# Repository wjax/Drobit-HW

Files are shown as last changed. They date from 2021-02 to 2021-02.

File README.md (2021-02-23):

# Drobit-HW
 This repository contains the electronic design and BOM files of the Drobit HW ecosystem.

 Drobit is a PPK (Post Processing Kinematics) solution for the UAV industry. Drobit allows to precisely geotag pictures taken by a camera on board the UAV allowing GCP-free (ground control point) photogrammetry surveys.

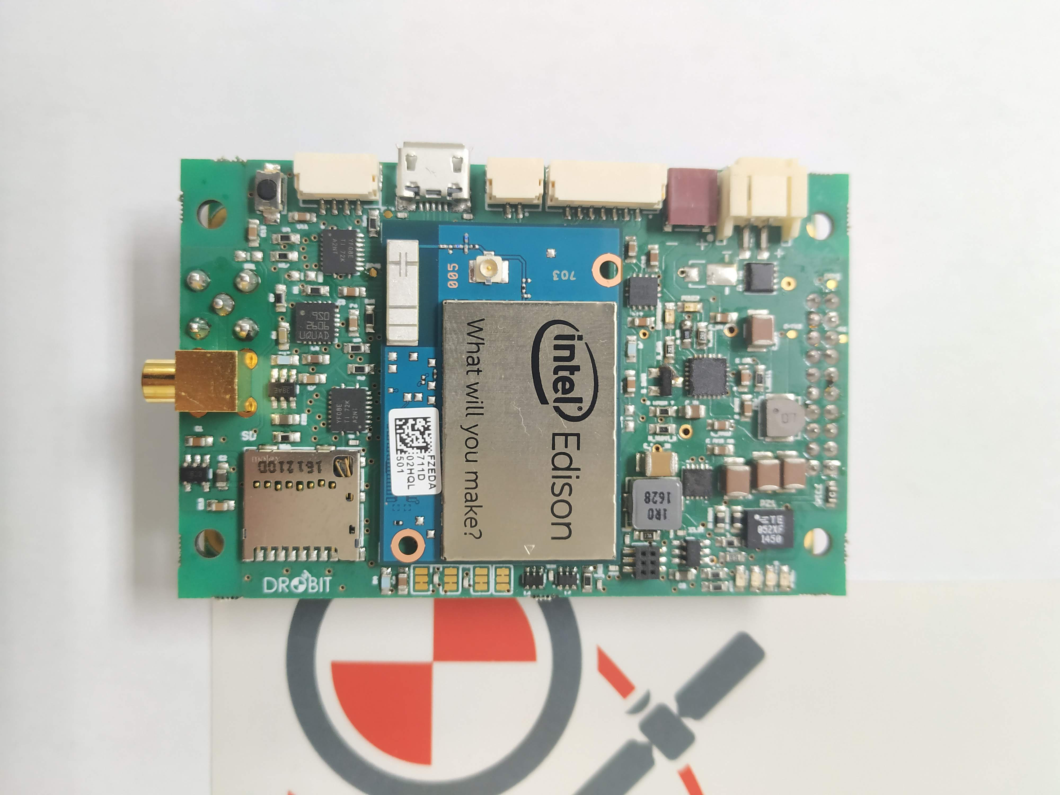
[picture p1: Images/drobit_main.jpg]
Drobit main board Drobit Main
  

 Drobit HW ecosystem is:
 * Drobit Main board
    * Intel Edison CPU
    * Dual-Freq GNSS Board from ComNav
    * 9Dof IMU
    * Batttery management 
 * Drobit Hotshoe board
    * Camera flash signal conditioning
    * 9Dof IMU 
 * Optional: External Button-LED board for cases
 * Optional: Micro connector breakboard

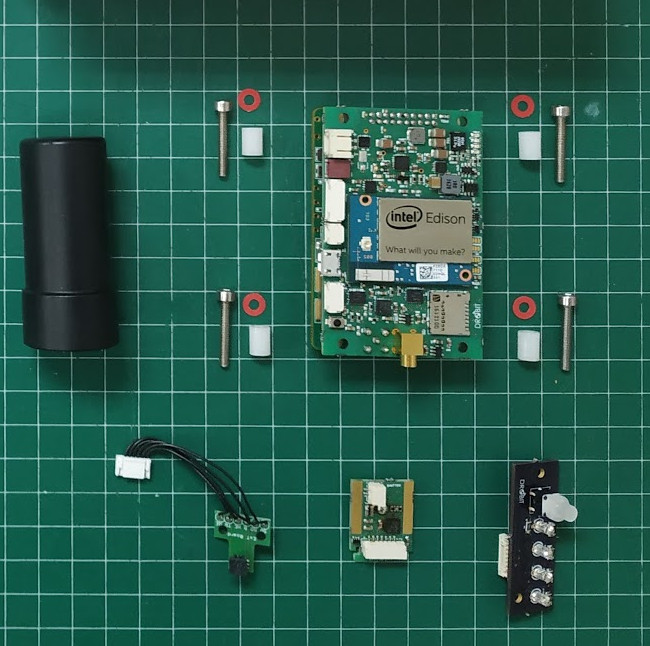
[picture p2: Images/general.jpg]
Drobit components
 
 
 ## History
 Drobit was created in 2016 by Jose Martinez Rubio and Jesús Alvarez in order to overcome one of the main limitations when doing UAV Photogrammetry applied to big survey areas.... the manual positioning of GCPs.

 Drobit has been used too as *Drobit Inspector* for Civil infrastructure inspection.

 As of today, Drobit has finished its commercial life and we decided to opensource both HW and SW.

 ## Theory of operation
 The idea behind drobit is to provide aerial imagery with super precise WGS84 coordinates of the lens nodal point. If that's the case, photogrammetry software like Agisoft Metashaper or Pix4D can reconstruct the terrain 3D model with centimeter accuracy (with no GCP).

 In order to do that Drobit incorporates a Dual Frequency Survey grade GPS (ComNav 501G) with a Heical Harxon Dual frecuency Antenna that provides 20Hz RAW GNSS observations. We will use Differential GPS as the main source of precise geopositioning.
 It also contains two 9dof IMU, one in the drobit main board and one in the drobit hotshoe board.

 The hotshoe board will be inserted into the camera hotshoe and will provide precise timing for every picture by sensing the flash trigger.

 In a photogrammetry UAV flight, drobit will record GNSS observations (for later postprocessing PPK) and will capture IMU orientation for both drobit main board and hotshoe board.

## Post Processing (PPK and coordinates translation)
 Later, in the office, Drobit PPK Software will obtain precise GPS (WGS84) coordinates from the antenna phase center by resolving the PPK against a GNSS Base receiver (Drobit base or any other manufacturer base with Rinex, even a CORS).

 In order to obtain the nodal camera point position, Drobit PPK Software needs to translate the GNSS antenna coordinate using IMU values and X,Y,Z offsets.

 Once finished, pictures are geotagged and a file containing picture name and precise coordinates is generated.

 Drobit PPK Software creates an kmz for google earth that allows to see cameras oriented and located in 3d space.

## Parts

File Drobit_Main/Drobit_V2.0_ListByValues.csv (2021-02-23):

Qty | Value | Part Num | Package | Parts
4 |  | * | PAD-JUMPER-3-2OF3_NC_BY_TRACE_YES_SILK_FULL_BOX | JP-DCIN, JP-ENABLE-UART2, JP-SCL, JP-SDA
1 |  | 455-1564-1-ND | JST-GH-2 | TRIG-IN
1 |  | 455-1566-1-ND | JST-GH-4 | UART-EXT
1 |  | 455-1569-1-ND | JST-GH-7 | TRIG-OUT
1 |  | 455-2524-1-ND | SM02B-SFHRS-TF | BATT
1 |  | 523-A-1JB | U.FL-A-1JB | X1
5 | 0.1UF | 810-CGA3E2X7R1E104K | 0603-CAP | C4, C7, C11, C12, C13
1 | 0.22UF | 810-C1608X7R1C224K | 0603-CAP | C5
1 | 0.033uF | 810-CGA3E2X7R1H333MA | 0603-CAP | C_BOOT
6 | 1.0UF | 810-CGA3E1X7R1E105K | 0603-CAP | C1, C3, C9, C10, C14, C_BAT
1 | 1.5uH | 81-FDSD0420-H-1R5MP3 | FDSD0420 | L_SW
1 | 1.8K | 667-ERJ-3GEYJ182V | 0603-RES | R_CHG
1 | 1.8K | 667-ERJ-3GEYJ182V | 0603-RES | R_PG
1 | 1UF | 810-CGA3E1X7R1E105K | 0603-CAP | C_PMID
2 | 2.2UF | 810-CGA3E1X5R1C225K | 0603-CAP | C15, C_DRV
2 | 4.7K | * | 0603-RES | R51, R52
1 | 4.7UF | 81-GRM18R60J475KE19D | 0603-CAP | C6
1 | 4.7UF | 810-C2012X5R1E226M | 0603-CAP | C_IN
1 | 10K | 667-ERJ-3EKF1002V | 0603-RES | R_VDPM_B
10 | 10K | 667-ERJ-3EKF1002V | 0603-RES | R1, R2, R3, R5, R6, R15, R17, R61, R62, R_ISET1
1 | 10NF | 810-CGA3E2X7R1H103K | 0603-CAP | C16
3 | 10UF | 810-C3225X7R1E106K | 1210 | C_DC5_OUT1, C_DC5_OUT2, C_OUTS
1 | 10UF | 810-C3225X7R1E106K | 1210 | C_SYS
3 | 10UF | 810-CGA4J1X5R1C106K | 0603-CAP | C2, C8, C22
1 | 22UF | 81-GRM32ER61E226ME5L | 1210 | C_DC5_IN
1 | 47K | 754-RR0816P-473D | 0603-RES | R10
1 | 71.5K | 667-ERJ-3EKF7152V | 0603-RES | R_VDPM_T
1 | 82 | 667-ERJ-3EKF82R0V | 0603-RES | R28
3 | 100K | 754-RR0510P-104D | 0603-RES | R4, R7, R18
2 | 105 | 667-ERJ-3EKF1050V | 0603-RES | R20, R24
1 | 180 | 667-ERJ-3GEYJ181V | 0603-RES | R19
1 | 270NF | 81-GRM188R71C274KA1D | 0603-CAP | C_DC5_SS
2 | 287 | 667-ERJ-3EKF2870V | 0603-RES | R9, R16
1 | 590 | 754-RR1220P-5900D-M | 0603-RES | R_ISET
1 | 0603L010YR | 576-0603L010YR | 0602 | PTC1
1 | 10103594-0001LF | 649-10103594-0001LF | POS-5 | USB
1 | BAT54C | 512-BAT54C | SOT23 | D_IUSB
2 | BLM18SG221TZ1-2.5A | 81-BLM18SG221TZ1D | 0603 | BLM5V1, BLM5V2
1 | BLUE - APT1608VBC/D | 604-APT1608VBC/D | LED-0603 | D-TRIGGER
1 | BQ24266 | 595-BQ24266RGER | QFN50P400X400X100-25N | CHARGER
2 | BSS138PS | 771-BSS138BKS115 | SOT363 | T2, T3
1 | COMNAV_501G | * | COMNAV_501G | U$1
1 | EDISON_CONNECTOR_FULLMOUNTING_HOLES | 798-DF40C70DS04V51 | EDISON_DAUGHTER | U2
1 | FR014H5JZ | 512-FR014H5JZ | FR014H5JZ | P_IN
1 | HM-TRLR-S | * | HM-TRLR-S | LINK
1 | JST_PH_G | 455-1749-1-ND | JST-PH-2-SMT-RA | PWR
1 | JUMPER-PAD-2-NOYES_SILK | * | PAD-JUMPER-2-NO_YES_SILK | JP_LINK
1 | LSM9DS0 | 497-13902-1-ND | LGA-24 | U1
10 | LXES15AAA1-133 | 81-LXES15AAA1-133 | 1005 | TVS1, TVS2, TVS3, TVS4, TVS5, TVS6, TVS7, TVS8, TVS9, TVS10
1 | M40-3100345R | 855-M40-3100345R | M40-3100345R | EXT-INTERFACE
1 | MCX-TECON-1-1337586-0 | 571-1-1337586-0 | 1-1337586-0 | U$2
2 | MIC2039 | 998-MIC2039EYM6T5 | SOT23-6 | 5VACCLIM, USBREG
1 | MIC52053.3V | 998-MIC5205-3.3YM5TR | SOT23-5 | U4
2 | ORANGE - APT1608SECK/J4-PRV | 604-APT1608SECKJ4PRV | LED-0603 | CHARGING, D-REC
1 | ROJO - APT1608SECK/J3- | 604-APT1608SECKJ3PRV | LED-0603 | POWER
1 | ROJO - APT1608SECK/J3-PRV | 604-APT1608SECKJ3PRV | LED-0603 | D-ON
1 | SDCARD | 538-104031-0811 | 1040310811 | SD
1 | SKRKAEE010 | 688-SKRKAE | SKRKAEE010 | SREC
1 | SPR5030T-1R0 | 652-SRP5030T-1R0M | SRP5030T-1R0 | L_DC5_SW
1 | TPS61232 | 595-TPS61232DRCR | SON-10 | DC5V
1 | TPS73501DRBT | 595-TPS73501DRBR | SON65P300X300X100-9N | DC3VLINK
5 | TPTP08R | * | TP08R | C-RX2, C-TX2, GP45, GP46, PPS
2 | TXS0108 | 595-TXS0108ERGYR | R-PVQFN-N20 | U7, U9
1 | V8PAN50-M3/I | 78-V8PAN50-M3/I | V8PAN50-M3/I | D_IN
1 | VERDE - APT1608ZGCK | 604-APT1608ZGCK | LED-0603 | D-SAT
1 | ZEN056V230A16YC | 650-ZEN056V230A16YC | ZEN056V230A16YC | PZ1

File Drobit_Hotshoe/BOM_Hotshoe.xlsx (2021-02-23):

ZAPATA PLACA PEQUEÑA
Qty x Placa | NUMERO | Value | Part Num | Package | Parts | Cantidad Total
1 | 1 |  | 455-1564-1-ND | JST-GH-2 | SHUTTER | 50 | Ojo Posicion. Huella no igual que placa grande
1 | 3 |  | 455-1569-1-ND | JST-GH-7 | DROBIT-IO | 50
1 | 6 | 0.1UF | 810-CGA3E2X7R1E104K | 0603-CAP | C4 | 135
1 | 7 | 0.22UF | 810-C1608X7R1C224K | 0603-CAP | C5 | 50
1 | 9 | 1.0UF | 810-CGA3E1X7R1E105K | 0603-CAP | C3 | 180
2 | 101 | 4.7K | 667-ERJ-3GEYJ472V | 0603-RES | R21, R22 | 50
1 | 15 | 4.7UF | 81-GRM18R60J475KE19D | 0603-CAP | C6 | 50
1 | 102 | 10K | 667-EXB-38V103JV | 0603-ARV | R1 | 25
1 | 39 | BSS138PS | 771-BSS138BKS115 | SOT363 | T1 | 75
1 | 43 | LSM9DS0 | 497-13902-1-ND | LGA-24 | U1 | 50
 |  | Compartidos ambas placas

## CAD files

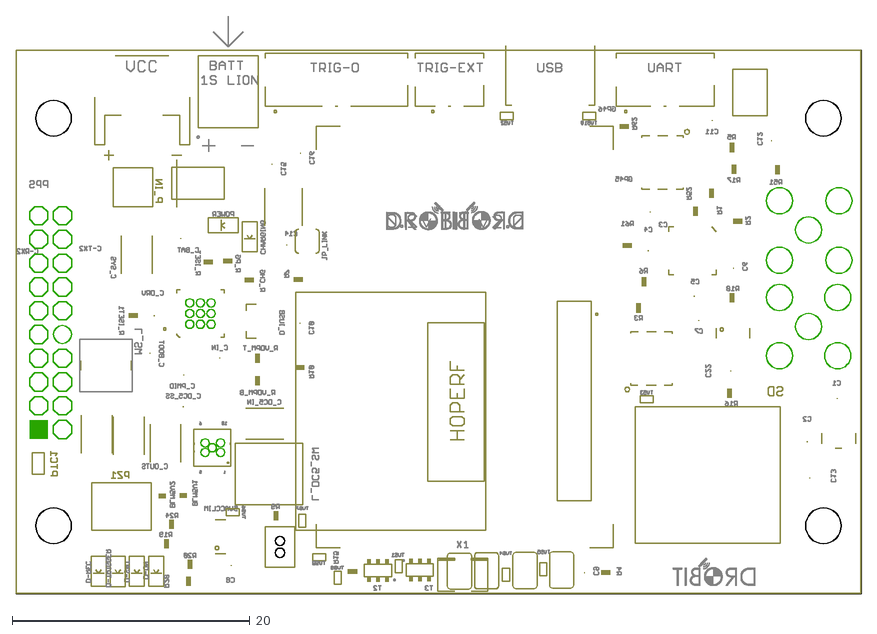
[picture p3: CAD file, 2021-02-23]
Drobit_Main/Drobit_V2.0.dxf
71.1 x 48.6

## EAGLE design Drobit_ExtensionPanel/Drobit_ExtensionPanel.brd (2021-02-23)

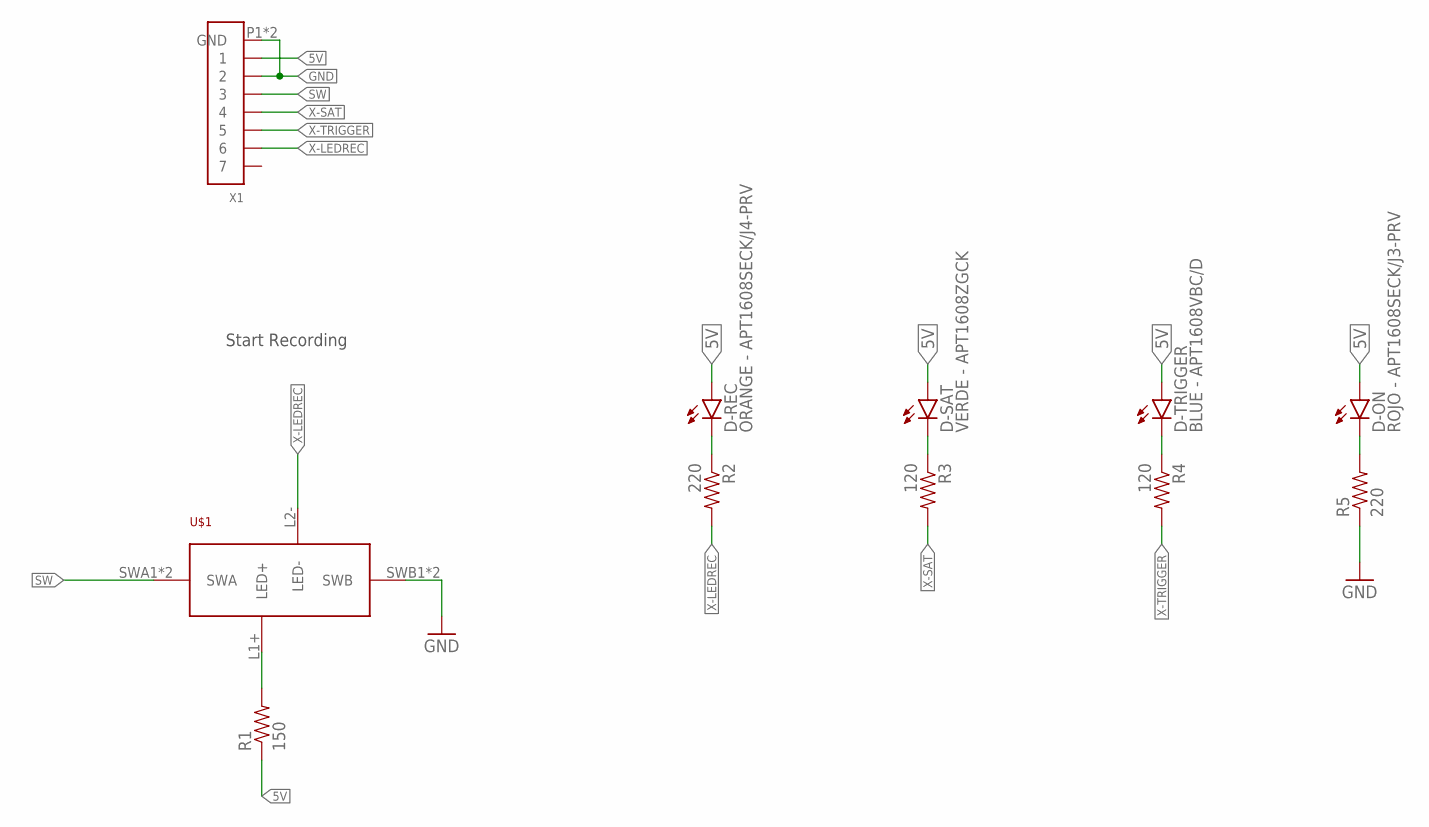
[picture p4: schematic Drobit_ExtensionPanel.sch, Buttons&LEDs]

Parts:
D-ON: ROJO - APT1608SECK/J3-PRV; LED3MM; PARTNO 604-APT1608SECKJ3PRV
D-REC: ORANGE - APT1608SECK/J4-PRV; LED3MM; PARTNO 604-APT1608SECKJ4PRV
D-SAT: VERDE - APT1608ZGCK; LED3MM; PARTNO 604-APT1608ZGCK
D-TRIGGER: BLUE - APT1608VBC/D; LED3MM; PARTNO 604-APT1608VBC/D
R1: 150; 1206
R2: 220; 1206; PARTNO 667-ERJ-3GEYJ181V
R3, R4: 120; 1206; PARTNO 667-ERJ-3EKF1050V
R5: 220; 1206; PARTNO 667-ERJ-3EKF82R0V
U$1: PUSH-LED; ITS13FV1ST
X1: CONN_7-1; JST-GH-7

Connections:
5V: D-ON.A, D-REC.A, D-SAT.A, D-TRIGGER.A, R1.1, X1.1
GND: R5.1, U$1.SWB1 (SWB), U$1.SWB2 (SWB), X1.2, X1.P1 (GND), X1.P2 (GND)
unnamed: R1.2, U$1.L1+ (LED+)
unnamed: D-ON.K (C), R5.2
SW: U$1.SWA1 (SWA), U$1.SWA2 (SWA), X1.3
X-LEDREC: R2.2, U$1.L2- (LED-), X1.6
X-LEDREC--: D-REC.K (C), R2.1
X-SAT: R3.2, X1.4
X-SAT--: D-SAT.K (C), R3.1
X-TRIGGER: R4.2, X1.5
X-TRIGGER--: D-TRIGGER.K (C), R4.1

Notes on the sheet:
Start Recording

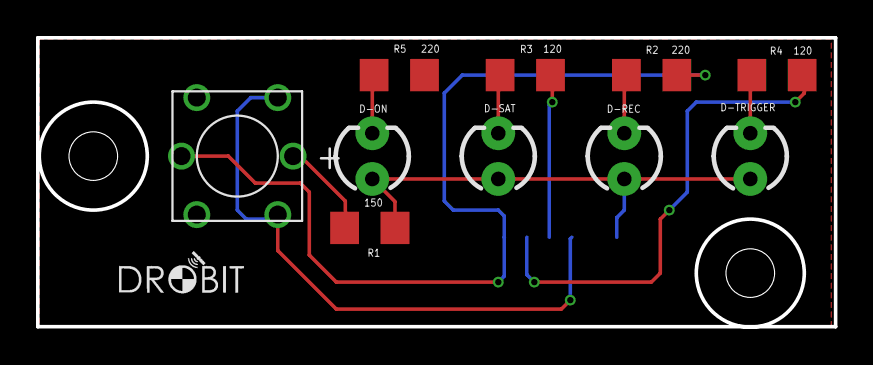
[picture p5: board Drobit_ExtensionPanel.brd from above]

Board: 2 copper layers, 44.3 x 16.0 mm, 11 parts (1 on the bottom side), 11 nets.

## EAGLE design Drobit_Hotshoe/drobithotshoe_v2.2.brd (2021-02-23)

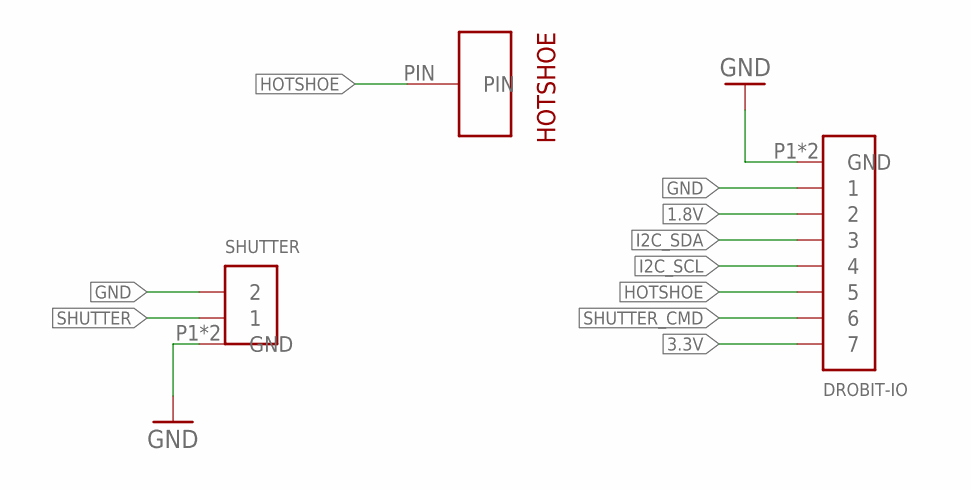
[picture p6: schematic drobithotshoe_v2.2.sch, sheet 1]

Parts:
DROBIT-IO: CONN_7-1; JST-GH-7; PARTNO 455-1569-1-ND
HOTSHOE: ZAPATA-MILMAX; MILMAX-807-22-001-30-000101; PARTNO NO_PONER
SHUTTER: CONN_2-1-GH-VERT; JST-GH-2-V; PARTNO 455-1564-1-ND

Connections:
1.8V: DROBIT-IO.2; also elsewhere on the board
3.3V: DROBIT-IO.7; also elsewhere on the board
GND: DROBIT-IO.1, DROBIT-IO.P1 (GND), DROBIT-IO.P2 (GND), SHUTTER.2, SHUTTER.P1 (GND), SHUTTER.P2 (GND); also elsewhere on the board
HOTSHOE: DROBIT-IO.5, HOTSHOE.PIN
I2C_SCL: DROBIT-IO.4; also elsewhere on the board
I2C_SDA: DROBIT-IO.3; also elsewhere on the board
SHUTTER: SHUTTER.1; also elsewhere on the board
SHUTTER_CMD: DROBIT-IO.6; also elsewhere on the board

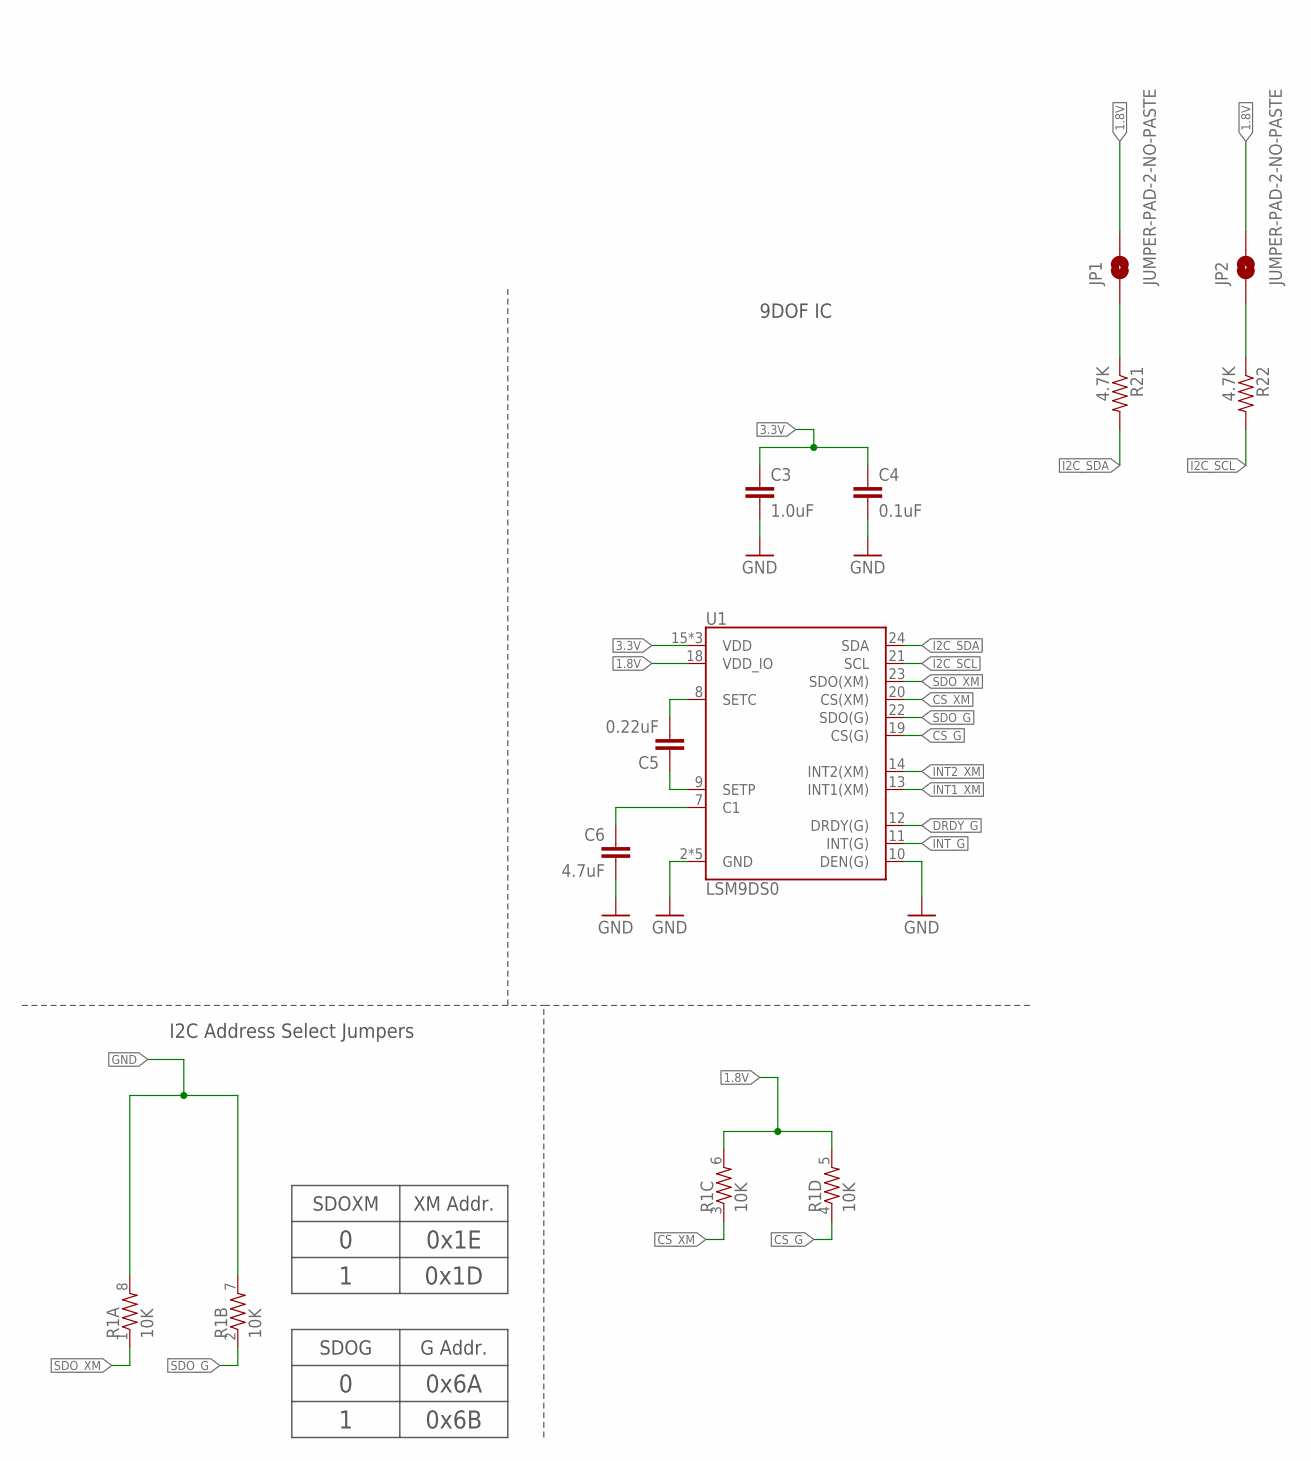
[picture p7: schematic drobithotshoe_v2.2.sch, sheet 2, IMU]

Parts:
C3: 1.0uF; 0603-CAP; PARTNO 810-CGA3E1X7R1E105K
C4: 0.1uF; 0603-CAP; PARTNO 810-CGA3E2X7R1E104K
C5: 0.22uF; 0603-CAP; PARTNO 810-C1608X7R1C224K
C6: 4.7uF; 0603-CAP; PARTNO 81-GRM18R60J475KE19D
JP1, JP2: JUMPER-PAD-2-NO-PASTE; PAD-JUMPER-2-NO_NO_SILK_PASTE; PARTNO N/A
R1: 10K; 0603-ARV; PARTNO 667-EXB-38V103JV
R21, R22: 4.7K; 0603-RES; PARTNO 667-ERJ-3GEYJ472V
U1: LSM9DS0; LGA-24; PARTNO 497-13902-1-ND

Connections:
1.8V: JP1.2, JP2.2, R1.5 (2), R1.6 (2), U1.18 (VDD_IO); also elsewhere on the board
3.3V: C3.1, C4.1, U1.15 (VDD), U1.16 (VDD), U1.17 (VDD); also elsewhere on the board
CS_G: R1.4 (1), U1.19 (CS(G))
CS_XM: R1.3 (1), U1.20 (CS(XM))
DRDY_G: U1.12 (DRDY(G))
GND: C3.2, C4.2, C6.2, R1.7 (2), R1.8 (2), U1.2 (GND), U1.3 (GND), U1.4 (GND), U1.5 (GND), U1.6 (GND), U1.10 (DEN(G)); also elsewhere on the board
I2C_SCL: R22.2, U1.21 (SCL); also elsewhere on the board
I2C_SDA: R21.2, U1.24 (SDA); also elsewhere on the board
INT1_XM: U1.13 (INT1(XM))
INT2_XM: U1.14 (INT2(XM))
INT_G: U1.11 (INT(G))
unnamed: C5.1, U1.9 (SETP)
unnamed: C5.2, U1.8 (SETC)
unnamed: C6.1, U1.7 (C1)
unnamed: JP1.1, R21.1
unnamed: JP2.1, R22.1
SDO_G: R1.2 (1), U1.22 (SDO(G))
SDO_XM: R1.1, U1.23 (SDO(XM))

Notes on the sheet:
I2C Address Select Jumpers
9DOF IC
SDOXM
XM Addr.
0x1E
0x1D
SDOG
G Addr.
0x6A
0x6B

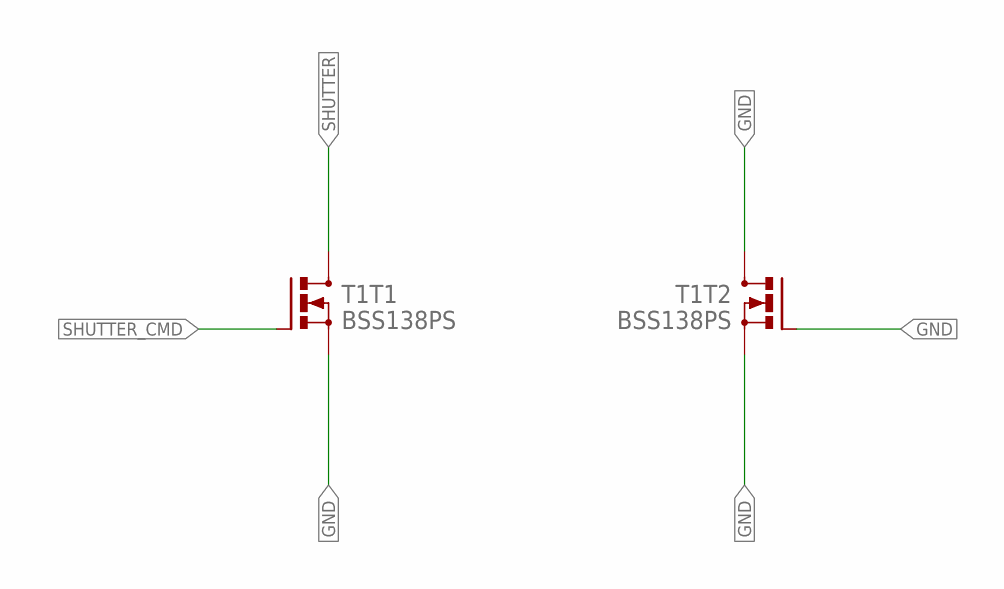
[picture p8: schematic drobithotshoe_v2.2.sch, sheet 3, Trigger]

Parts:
T1: BSS138PS; SOT363; PARTNO 771-BSS138BKS115

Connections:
GND: T1.1 (S), T1.3 (D), T1.4 (S), T1.5 (G); also elsewhere on the board
SHUTTER: T1.6 (D); also elsewhere on the board
SHUTTER_CMD: T1.2 (G); also elsewhere on the board

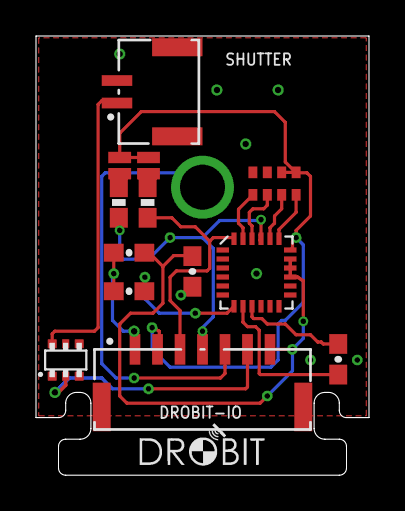
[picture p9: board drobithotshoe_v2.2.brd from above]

Board: 2 copper layers, 18.5 x 24.4 mm, 14 parts (1 on the bottom side), 17 nets.

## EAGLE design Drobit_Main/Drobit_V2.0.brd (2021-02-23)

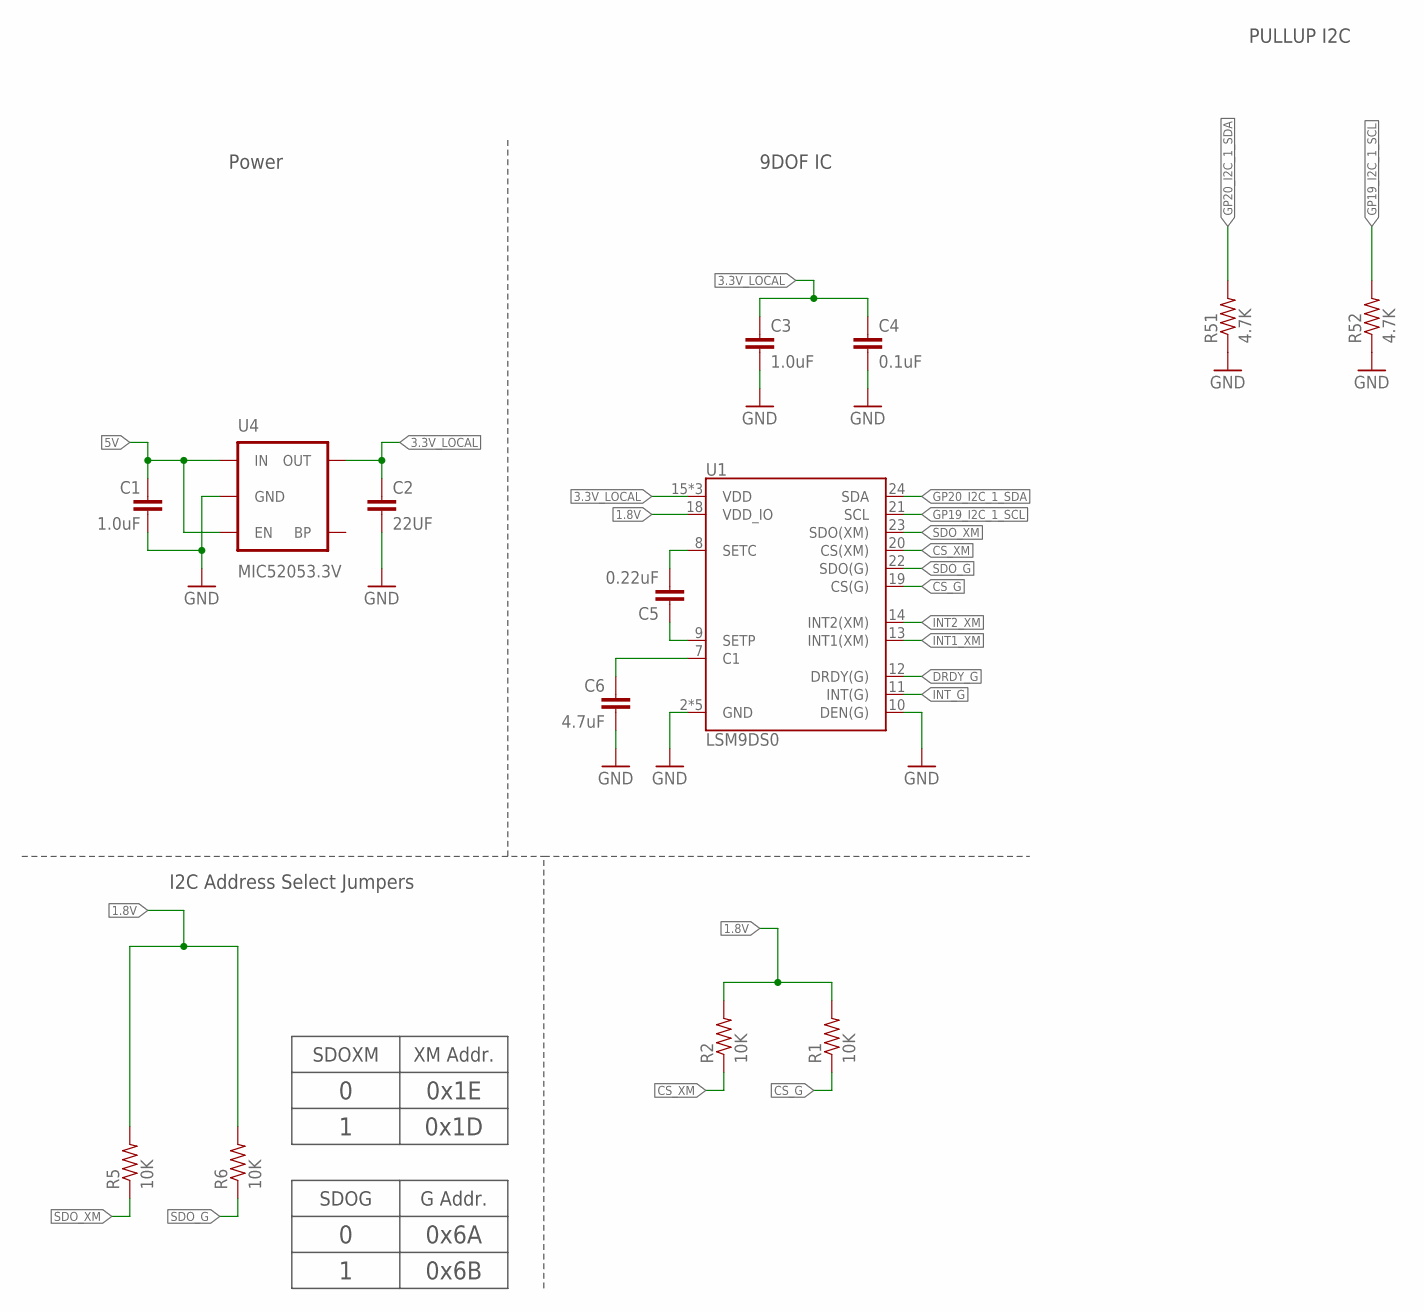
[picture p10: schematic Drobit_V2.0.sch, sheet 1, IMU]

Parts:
C1, C3: 1.0uF; 0603-CAP; PARTNO 810-CGA3E1X7R1E105K
C2: 22UF; 0603-CAP; PARTNO 810-C1608X5R1A226M
C4: 0.1uF; 0603-CAP; PARTNO 810-CGA3E2X7R1E104K
C5: 0.22uF; 0603-CAP; PARTNO 810-C1608X7R1C224K
C6: 4.7uF; 0603-CAP; PARTNO 81-GRM18R60J475KE19D
R1, R2, R5, R6: 10K; 0603-RES; PARTNO 667-ERJ-3EKF1002V
R51, R52: 4.7K; 0603-RES; PARTNO NO_PONER
U1: LSM9DS0; LGA-24; PARTNO 497-13902-1-ND
U4: MIC52053.3V; SOT23-5; PARTNO 998-MIC5205-3.3YM5TR

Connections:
1.8V: R1.2, R2.2, R5.2, R6.2, U1.18 (VDD_IO); also elsewhere on the board
3.3V_LOCAL: C2.1, C3.1, C4.1, U1.15 (VDD), U1.16 (VDD), U1.17 (VDD), U4.5 (OUT); also elsewhere on the board
5V: C1.1, U4.1 (IN), U4.3 (EN); also elsewhere on the board
CS_G: R1.1, U1.19 (CS(G))
CS_XM: R2.1, U1.20 (CS(XM))
DRDY_G: U1.12 (DRDY(G))
GND: C1.2, C2.2, C3.2, C4.2, C6.2, R51.1, R52.1, U1.2 (GND), U1.3 (GND), U1.4 (GND), U1.5 (GND), U1.6 (GND), U1.10 (DEN(G)), U4.2 (GND); also elsewhere on the board
GP19_I2C_1_SCL: R52.2, U1.21 (SCL); also elsewhere on the board
GP20_I2C_1_SDA: R51.2, U1.24 (SDA); also elsewhere on the board
INT1_XM: U1.13 (INT1(XM))
INT2_XM: U1.14 (INT2(XM))
INT_G: U1.11 (INT(G))
unnamed: C5.1, U1.9 (SETP)
unnamed: C5.2, U1.8 (SETC)
unnamed: C6.1, U1.7 (C1)
SDO_G: R6.1, U1.22 (SDO(G))
SDO_XM: R5.1, U1.23 (SDO(XM))

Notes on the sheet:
I2C Address Select Jumpers
9DOF IC
Power
SDOXM
XM Addr.
0x1E
0x1D
SDOG
G Addr.
0x6A
0x6B
PULLUP I2C

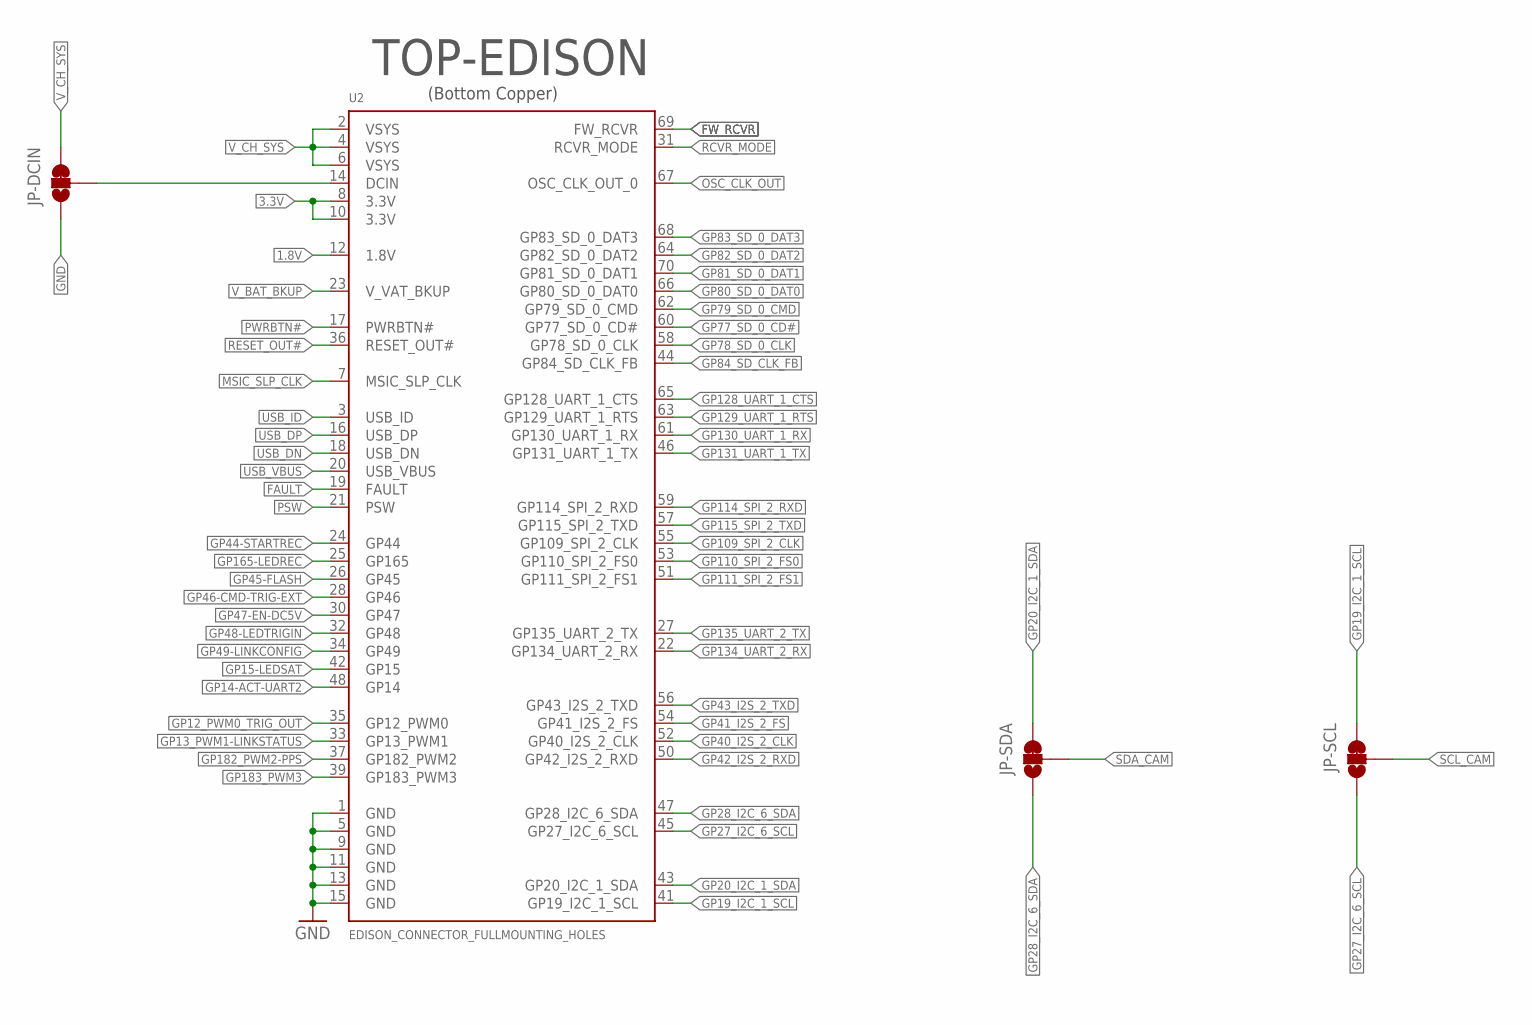
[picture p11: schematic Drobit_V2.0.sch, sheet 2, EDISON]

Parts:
JP-DCIN: JUMPER-PAD-3-2OF3_NC_BY_TRACE_SMALL; PAD-JUMPER-3-2OF3_NC_BY_TRACE_YES_SILK_FULL_BOX
JP-SCL: JUMPER-PAD-3-2OF3_NC_BY_TRACE_SMALL; PAD-JUMPER-3-2OF3_NC_BY_TRACE_YES_SILK_FULL_BOX
JP-SDA: JUMPER-PAD-3-2OF3_NC_BY_TRACE_SMALL; PAD-JUMPER-3-2OF3_NC_BY_TRACE_YES_SILK_FULL_BOX
U2: EDISON_CONNECTOR_FULLMOUNTING_HOLES; EDISON_DAUGHTER; PARTNO 798-DF40C70DS04V51

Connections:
1.8V: U2.12 (1.8V); also elsewhere on the board
3.3V: U2.8 (3.3V), U2.10 (3.3V); also elsewhere on the board
FAULT: U2.19 (FAULT); also elsewhere on the board
FW_RCVR: U2.69 (FW_RCVR)
GND: JP-DCIN.1, U2.1 (GND), U2.5 (GND), U2.9 (GND), U2.11 (GND), U2.13 (GND), U2.15 (GND); also elsewhere on the board
GP12_PWM0_TRIG_OUT: U2.35 (GP12_PWM0); also elsewhere on the board
GP13_PWM1-LINKSTATUS: U2.33 (GP13_PWM1); also elsewhere on the board
GP14-ACT-UART2: U2.48 (GP14); also elsewhere on the board
GP15-LEDSAT: U2.42 (GP15); also elsewhere on the board
GP19_I2C_1_SCL: JP-SCL.3, U2.41 (GP19_I2C_1_SCL); also elsewhere on the board
GP20_I2C_1_SDA: JP-SDA.3, U2.43 (GP20_I2C_1_SDA); also elsewhere on the board
GP27_I2C_6_SCL: JP-SCL.1, U2.45 (GP27_I2C_6_SCL)
GP28_I2C_6_SDA: JP-SDA.1, U2.47 (GP28_I2C_6_SDA)
GP40_I2S_2_CLK: U2.52 (GP40_I2S_2_CLK)
GP41_I2S_2_FS: U2.54 (GP41_I2S_2_FS)
GP42_I2S_2_RXD: U2.50 (GP42_I2S_2_RXD)
GP43_I2S_2_TXD: U2.56 (GP43_I2S_2_TXD)
GP44-STARTREC: U2.24 (GP44); also elsewhere on the board
GP45-FLASH: U2.26 (GP45); also elsewhere on the board
GP46-CMD-TRIG-EXT: U2.28 (GP46); also elsewhere on the board
GP47-EN-DC5V: U2.30 (GP47); also elsewhere on the board
GP48-LEDTRIGIN: U2.32 (GP48); also elsewhere on the board
GP49-LINKCONFIG: U2.34 (GP49); also elsewhere on the board
GP77_SD_0_CD#: U2.60 (GP77_SD_0_CD#); also elsewhere on the board
GP78_SD_0_CLK: U2.58 (GP78_SD_0_CLK); also elsewhere on the board
GP79_SD_0_CMD: U2.62 (GP79_SD_0_CMD); also elsewhere on the board
GP80_SD_0_DAT0: U2.66 (GP80_SD_0_DAT0); also elsewhere on the board
GP81_SD_0_DAT1: U2.70 (GP81_SD_0_DAT1); also elsewhere on the board
GP82_SD_0_DAT2: U2.64 (GP82_SD_0_DAT2); also elsewhere on the board
GP83_SD_0_DAT3: U2.68 (GP83_SD_0_DAT3); also elsewhere on the board
GP84_SD_CLK_FB: U2.44 (GP84_SD_CLK_FB); also elsewhere on the board
GP109_SPI_2_CLK: U2.55 (GP109_SPI_2_CLK)
GP110_SPI_2_FS0: U2.53 (GP110_SPI_2_FS0)
GP111_SPI_2_FS1: U2.51 (GP111_SPI_2_FS1)
GP114_SPI_2_RXD: U2.59 (GP114_SPI_2_RXD)
GP115_SPI_2_TXD: U2.57 (GP115_SPI_2_TXD)
GP128_UART_1_CTS: U2.65 (GP128_UART_1_CTS)
GP129_UART_1_RTS: U2.63 (GP129_UART_1_RTS)
GP130_UART_1_RX: U2.61 (GP130_UART_1_RX); also elsewhere on the board
GP131_UART_1_TX: U2.46 (GP131_UART_1_TX); also elsewhere on the board
GP134_UART_2_RX: U2.22 (GP134_UART_2_RX); also elsewhere on the board
GP135_UART_2_TX: U2.27 (GP135_UART_2_TX); also elsewhere on the board
GP165-LEDREC: U2.25 (GP165); also elsewhere on the board
GP182_PWM2-PPS: U2.37 (GP182_PWM2); also elsewhere on the board
GP183_PWM3: U2.39 (GP183_PWM3)
MSIC_SLP_CLK: U2.7 (MSIC_SLP_CLK)
unnamed: JP-DCIN.2, U2.14 (DCIN)
OSC_CLK_OUT: U2.67 (OSC_CLK_OUT_0)
PSW: U2.21 (PSW); also elsewhere on the board
PWRBTN#: U2.17 (PWRBTN#); also elsewhere on the board
RCVR_MODE: U2.31 (RCVR_MODE)
RESET_OUT#: U2.36 (RESET_OUT#)
SCL_CAM: JP-SCL.2; also elsewhere on the board
SDA_CAM: JP-SDA.2; also elsewhere on the board
USB_DN: U2.18 (USB_DN); also elsewhere on the board
USB_DP: U2.16 (USB_DP); also elsewhere on the board
USB_ID: U2.3 (USB_ID); also elsewhere on the board
USB_VBUS: U2.20 (USB_VBUS); also elsewhere on the board
V_BAT_BKUP: U2.23 (V_VAT_BKUP)
V_CH_SYS: JP-DCIN.3, U2.2 (VSYS), U2.4 (VSYS), U2.6 (VSYS); also elsewhere on the board

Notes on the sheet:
TOP-EDISON
(Bottom Copper)

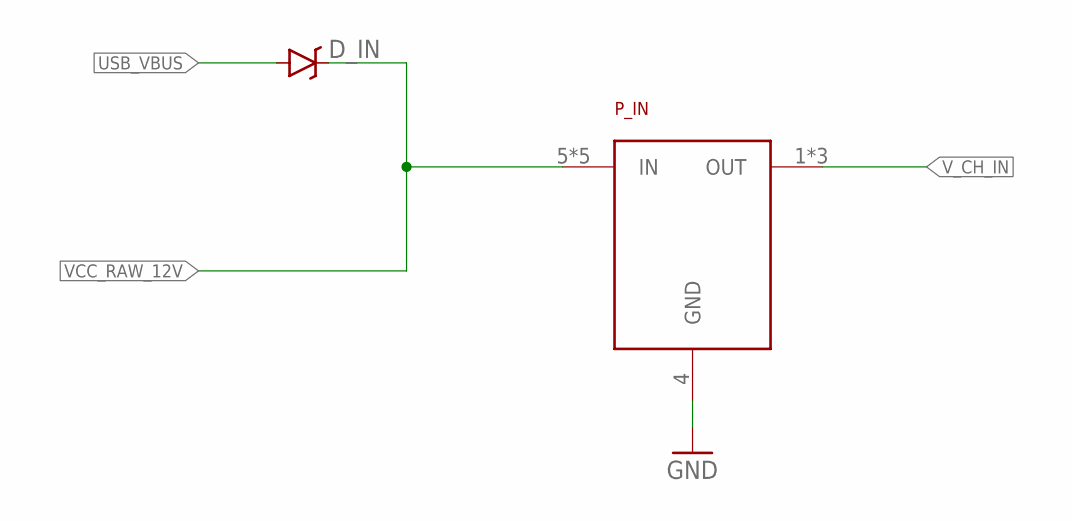
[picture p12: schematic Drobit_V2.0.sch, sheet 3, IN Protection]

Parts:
D_IN: V8PAN50-M3/I; PARTNO NO_PONER
P_IN: FR014H5JZ; PARTNO 512-FR014H5JZ

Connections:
GND: P_IN.4 (GND); also elsewhere on the board
USB_VBUS: D_IN.A; also elsewhere on the board
VCC_RAW_12V: D_IN.C, P_IN.5 (IN), P_IN.6 (IN), P_IN.7 (IN), P_IN.8 (IN), P_IN.PAD (IN); also elsewhere on the board
V_CH_IN: P_IN.1 (OUT), P_IN.2 (OUT), P_IN.3 (OUT); also elsewhere on the board

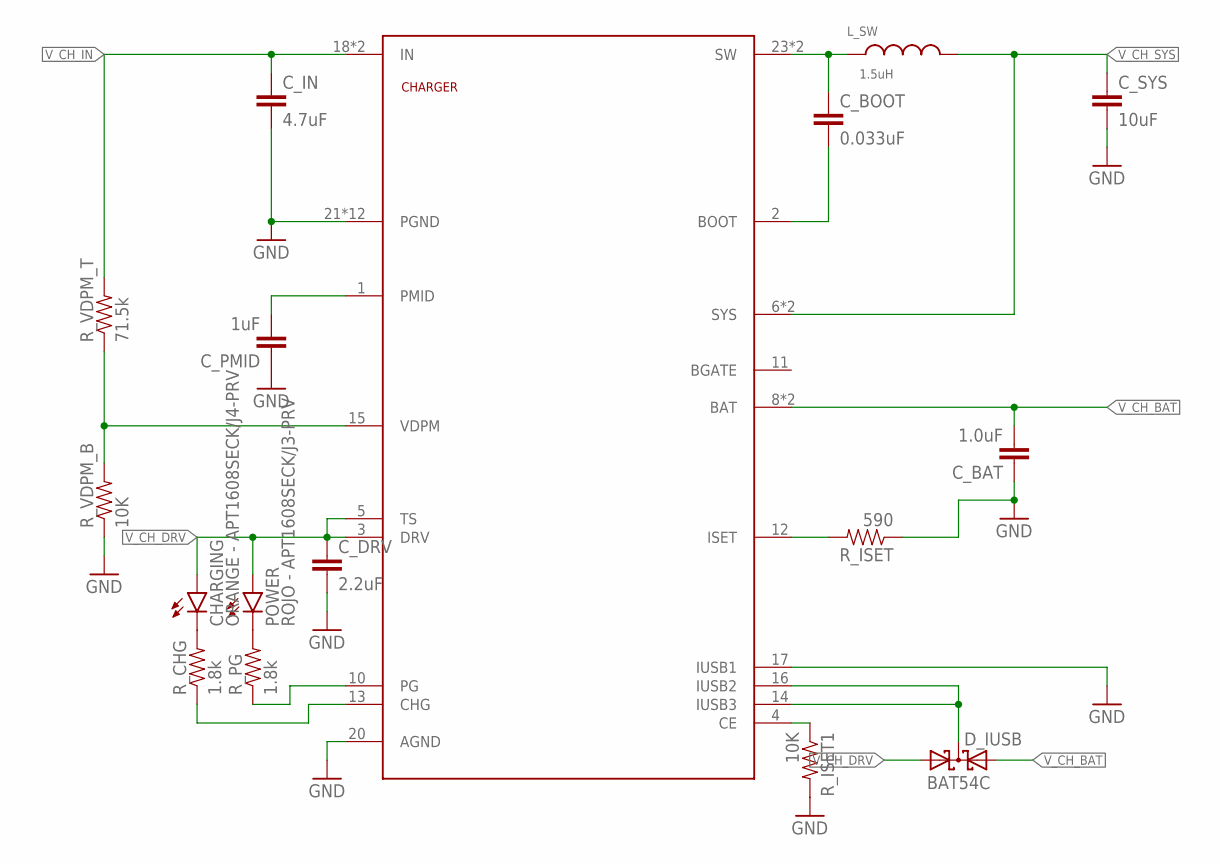
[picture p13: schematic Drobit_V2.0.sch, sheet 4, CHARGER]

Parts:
CHARGER: BQ24266; QFN50P400X400X100-25N; PARTNO 595-BQ24266RGER
CHARGING: ORANGE - APT1608SECK/J4-PRV; LED-0603; PARTNO 604-APT1608SECKJ4PRV
C_BAT: 1.0uF; 0603-CAP; PARTNO 810-CGA3E1X7R1E105K
C_BOOT: 0.033uF; 0603-CAP; PARTNO 810-CGA3E2X7R1H333MA
C_DRV: 2.2uF; 0603-CAP; PARTNO 810-CGA3E1X5R1C225K
C_IN: 4.7uF; 0603-CAP; PARTNO 810-C2012X5R1E226M
C_PMID: 1uF; 0603-CAP; PARTNO 810-CGA3E1X7R1E105K
C_SYS: 10uF; 1210; PARTNO 810-C3225X7R1E106K
D_IUSB: BAT54C; SOT23; PARTNO 512-BAT54C
L_SW: 1.5uH; FDSD0420; PARTNO 81-FDSD0420-H-1R5MP3
POWER: ROJO - APT1608SECK/J3-PRV; LED-0603; PARTNO 604-APT1608SECKJ3PRV
R_CHG: 1.8k; 0603-RES; PARTNO 667-ERJ-3GEYJ182V
R_ISET: 590; 0603-RES; PARTNO 754-RR0816P-5900D75A
R_ISET1: 10K; 0603-RES; PARTNO 667-ERJ-3EKF1002V
R_PG: 1.8k; 0603-RES; PARTNO 667-ERJ-3GEYJ182V
R_VDPM_B: 10K; 0603-RES; PARTNO 667-ERJ-3EKF1002V
R_VDPM_T: 71.5k; 0603-RES; PARTNO 667-ERJ-3EKF7152V

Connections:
GND: CHARGER.17 (IUSB1), CHARGER.20 (AGND), CHARGER.21 (PGND), CHARGER.22 (PGND), CHARGER.25 (PGND), CHARGER.P$2 (PGND), CHARGER.P$3 (PGND), CHARGER.P$4 (PGND), CHARGER.P$5 (PGND), CHARGER.P$6 (PGND), CHARGER.P$7 (PGND), CHARGER.P$8 (PGND), CHARGER.P$9 (PGND), CHARGER.P$10 (PGND), C_BAT.1, C_DRV.2, C_IN.2, C_PMID.1, C_SYS.2, R_ISET.1, R_ISET1.2, R_VDPM_B.1; also elsewhere on the board
unnamed: CHARGER.4 (CE), R_ISET1.1
unnamed: POWER.C, R_PG.2
unnamed: CHARGING.C, R_CHG.2
unnamed: CHARGER.10 (PG), R_PG.1
unnamed: CHARGER.13 (CHG), R_CHG.1
unnamed: CHARGER.2 (BOOT), C_BOOT.2
unnamed: CHARGER.12 (ISET), R_ISET.2
unnamed: CHARGER.14 (IUSB3), CHARGER.16 (IUSB2), D_IUSB.3 (CC)
V_CH_BAT: CHARGER.8 (BAT), CHARGER.9 (BAT), C_BAT.2, D_IUSB.2 (A2); also elsewhere on the board
V_CH_DPM: CHARGER.15 (VDPM), R_VDPM_B.2, R_VDPM_T.1
V_CH_DRV: CHARGER.3 (DRV), CHARGER.5 (TS), CHARGING.A, C_DRV.1, D_IUSB.1 (A1), POWER.A
V_CH_IN: CHARGER.18 (IN), CHARGER.19 (IN), C_IN.1, R_VDPM_T.2; also elsewhere on the board
V_CH_PMID: CHARGER.1 (PMID), C_PMID.2
V_CH_SW: CHARGER.23 (SW), CHARGER.24 (SW), C_BOOT.1, L_SW.1
V_CH_SYS: CHARGER.6 (SYS), CHARGER.7 (SYS), C_SYS.1, L_SW.2; also elsewhere on the board

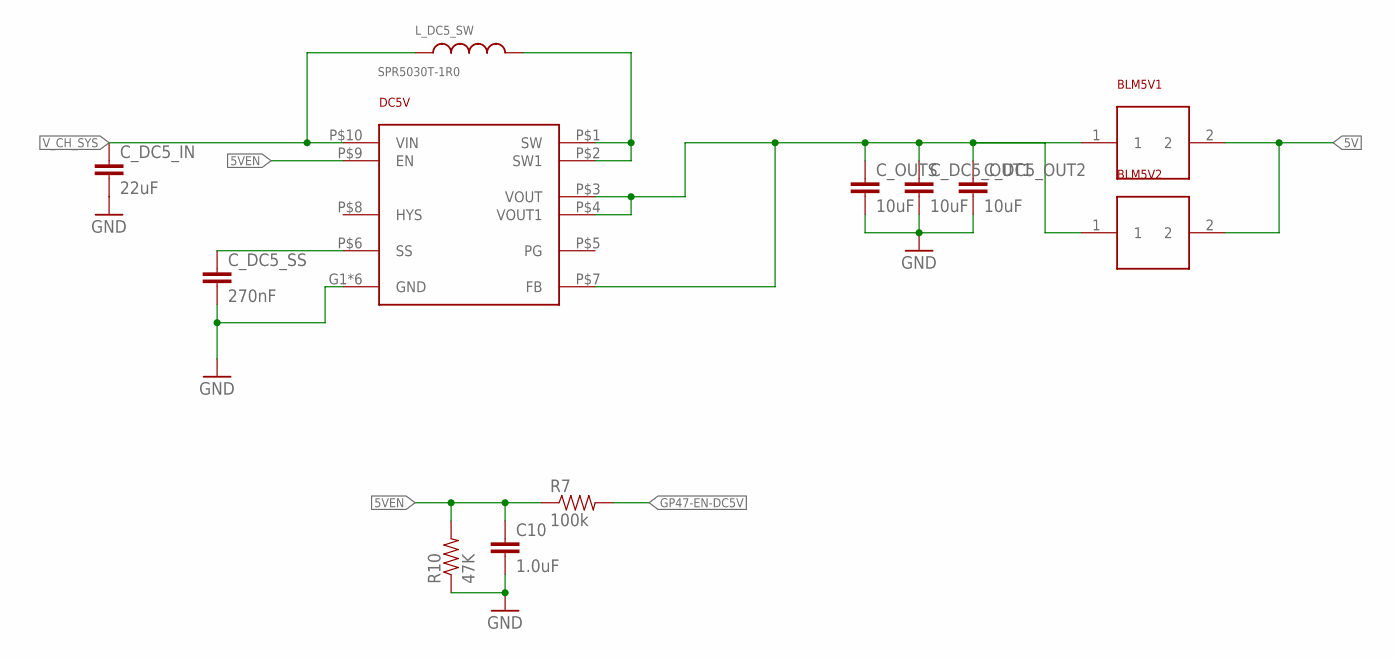
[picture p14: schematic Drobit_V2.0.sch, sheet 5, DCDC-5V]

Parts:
BLM5V1, BLM5V2: BLM18SG221TZ1-2.5A; 0603; PARTNO 81-BLM18SG221TZ1D
C10: 1.0uF; 0603-CAP; PARTNO 810-CGA3E1X7R1E105K
C_DC5_IN: 22uF; 1210; PARTNO 81-GRM32ER61E226ME5L
C_DC5_OUT1, C_DC5_OUT2: 10uF; 1210; PARTNO 810-C3225X7R1E106K
C_DC5_SS: 270nF; 0603-CAP; PARTNO 81-GRM188R71C274KA1D
C_OUTS: 10uF; 1210; PARTNO 810-C3225X7R1E106K
DC5V: TPS61232; SON-10; PARTNO 595-TPS61232DRCR
L_DC5_SW: SPR5030T-1R0; SRP5030T-1R0; PARTNO 652-SRP5030T-1R0M
R7: 100k; 0603-RES; PARTNO 594-MCT06030C1003FP5
R10: 47K; 0603-RES; PARTNO NO_PONER

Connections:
5V: BLM5V1.2, BLM5V2.2; also elsewhere on the board
5VEN: C10.1, DC5V.P$9 (EN), R7.1, R10.2
5VRAW: BLM5V1.1, BLM5V2.1, C_DC5_OUT1.1, C_DC5_OUT2.1, C_OUTS.1, DC5V.P$3 (VOUT), DC5V.P$4 (VOUT1), DC5V.P$7 (FB)
GND: C10.2, C_DC5_IN.2, C_DC5_OUT1.2, C_DC5_OUT2.2, C_DC5_SS.2, C_OUTS.2, DC5V.G1 (GND), DC5V.G2 (GND), DC5V.G3 (GND), DC5V.G4 (GND), DC5V.G5 (GND), DC5V.PAD (GND), R10.1; also elsewhere on the board
GP47-EN-DC5V: R7.2; also elsewhere on the board
V_CH_SYS: C_DC5_IN.1, DC5V.P$10 (VIN), L_DC5_SW.P$1 (1); also elsewhere on the board
V_DC5_SS: C_DC5_SS.1, DC5V.P$6 (SS)
V_DC5_SW: DC5V.P$1 (SW), DC5V.P$2 (SW1), L_DC5_SW.P$2 (2)

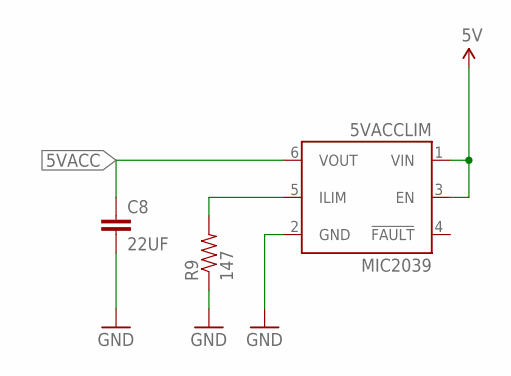
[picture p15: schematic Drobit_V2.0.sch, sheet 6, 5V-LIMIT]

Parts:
5VACCLIM: MIC2039; SOT23-6; PARTNO 998-MIC2039EYM6T5
C8: 22UF; 0603-CAP; PARTNO 810-C1608X5R1A226M
R9: 147; 0603-RES; PARTNO 754-RR0816P-1470D17A

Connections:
5V: 5VACCLIM.1 (VIN), 5VACCLIM.3 (EN); also elsewhere on the board
5VACC: 5VACCLIM.6 (VOUT), C8.1; also elsewhere on the board
GND: 5VACCLIM.2 (GND), C8.2, R9.1; also elsewhere on the board
unnamed: 5VACCLIM.5 (ILIM), R9.2


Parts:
PTC1: 0603L010YR; 0602; PARTNO 576-0603L010YR
PZ1: ZEN056V230A16YC; PARTNO 650-ZEN056V230A16YC
U$1: COMNAV_501G
U$2: MCX-TECON-1-1337586-0; 1-1337586-0; PARTNO 571-1-1337586-0

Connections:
5V: PZ1.IN; also elsewhere on the board
C-COM2RX: U$1.COM2_RX; also elsewhere on the board
C-COM2TX: U$1.COM2_TX; also elsewhere on the board
C-COM3RX: U$1.COM3_RX
C-COM3TX: U$1.COM3_TX
C-EVENT: U$1.EVENT; also elsewhere on the board
E-GP182_PWM2-PPS: U$1.PPS; also elsewhere on the board
E-UART1RX: U$1.COM1_TX; also elsewhere on the board
E-UART1TX: U$1.COM1_RX; also elsewhere on the board
GND: PZ1.GND, U$1.GNDA, U$1.GNDA1, U$1.GNDA2, U$1.GNDA3, U$1.GND_1, U$1.GND_2, U$1.GND_3, U$1.GND_4, U$2.GND1, U$2.GND2, U$2.GND3, U$2.GND4; also elsewhere on the board
unnamed: PTC1.P$2 (O), U$1.LNA_PWR
unnamed: PTC1.P$1 (I), PZ1.OUT, U$1.VIN
unnamed: U$1.ANT, U$2.ANT


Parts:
C9: 1.0uF; 0603-CAP; PARTNO 810-CGA3E1X7R1E105K
C11, C12: 0.1uF; 0603-CAP; PARTNO 810-CGA3E2X7R1E104K
JP-ENABLE-UART2: JUMPER-PAD-3-2OF3_NC_BY_TRACE_SMALL; PAD-JUMPER-3-2OF3_NC_BY_TRACE_YES_SILK_FULL_BOX
R4: 100k; 0603-RES; PARTNO 594-MCT06030C1003FP5
U7: TXS0108; R-PVQFN-N20; PARTNO 595-TXS0108ERGYR

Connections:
1.8V: C12.2, JP-ENABLE-UART2.3, U7.2 (VCCA); also elsewhere on the board
3.3V: C11.2, U7.19 (VCCB); also elsewhere on the board
C-EVENT: U7.13 (B7); also elsewhere on the board
E-GP13_PWM1-LINKSTATUS: U7.15 (B5); also elsewhere on the board
E-GP46-CMD-TRIG-EXT: U7.14 (B6); also elsewhere on the board
E-GP49-LINKCONFIG: U7.12 (B8); also elsewhere on the board
E-UART1RX: U7.17 (B3); also elsewhere on the board
E-UART1TX: U7.16 (B4); also elsewhere on the board
E-UART2RX: U7.20 (B1); also elsewhere on the board
E-UART2TX: U7.18 (B2); also elsewhere on the board
GND: C9.2, C11.1, C12.1, U7.11 (GND), U7.EPAD (GND); also elsewhere on the board
GP13_PWM1-LINKSTATUS: U7.6 (A5); also elsewhere on the board
GP14: JP-ENABLE-UART2.2, U7.10 (OE)
GP14-ACT-UART2: R4.2; also elsewhere on the board
GP45-FLASH: U7.8 (A7); also elsewhere on the board
GP46-CMD-TRIG-EXT: U7.7 (A6); also elsewhere on the board
GP49-LINKCONFIG: U7.9 (A8); also elsewhere on the board
GP130_UART_1_RX: U7.4 (A3); also elsewhere on the board
GP131_UART_1_TX: U7.5 (A4); also elsewhere on the board
GP134_UART_2_RX: U7.1 (A1); also elsewhere on the board
GP135_UART_2_TX: U7.3 (A2); also elsewhere on the board
unnamed: C9.1, JP-ENABLE-UART2.1, R4.1

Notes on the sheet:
Mecanismo para activar el conversor solo cuando se haya arrancado Edison evitando así que entre señal por UART2 afectando a U-boot La red RC es necesaria para eliminar un pulso al arranque de Edison que pone esta señal a nivel alto durante 5ms

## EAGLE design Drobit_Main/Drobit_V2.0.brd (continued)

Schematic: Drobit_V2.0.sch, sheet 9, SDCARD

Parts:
C7, C13: 0.1uF; 0603-CAP; PARTNO 810-CGA3E2X7R1E104K
SD: SDCARD; 1040310811; PARTNO 538-104031-0811
U9: TXS0108; R-PVQFN-N20; PARTNO 595-TXS0108ERGYR

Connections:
1.8V: C7.1, U9.2 (VCCA), U9.10 (OE); also elsewhere on the board
3.3V: C13.1, SD.D4, U9.19 (VCCB); also elsewhere on the board
E-GP182_PWM2-PPS: U9.12 (B8); also elsewhere on the board
GND: C7.2, C13.2, SD.CD2, SD.D6, SD.GND, SD.GND1 (GND), SD.GND2 (GND), SD.GND3 (GND), U9.11 (GND), U9.EPAD (GND); also elsewhere on the board
GP77_SD_0_CD#: SD.CD1; also elsewhere on the board
GP78_SD_0_CLK: U9.5 (A4); also elsewhere on the board
GP79_SD_0_CMD: U9.4 (A3); also elsewhere on the board
GP80_SD_0_DAT0: U9.6 (A5); also elsewhere on the board
GP81_SD_0_DAT1: U9.7 (A6); also elsewhere on the board
GP82_SD_0_DAT2: U9.1 (A1); also elsewhere on the board
GP83_SD_0_DAT3: U9.3 (A2); also elsewhere on the board
GP84_SD_CLK_FB: U9.8 (A7); also elsewhere on the board
GP182_PWM2-PPS: U9.9 (A8); also elsewhere on the board
unnamed: SD.D1, U9.20 (B1)
unnamed: SD.D2, U9.18 (B2)
unnamed: SD.D3, U9.17 (B3)
unnamed: SD.D7, U9.15 (B5)
unnamed: SD.D8, U9.14 (B6)
SCK: SD.D5, U9.13 (B7), U9.16 (B4)

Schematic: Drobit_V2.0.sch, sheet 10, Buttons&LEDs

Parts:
D-ON: ROJO - APT1608SECK/J3-PRV; LED-0603; PARTNO 604-APT1608SECKJ3PRV
D-REC: ORANGE - APT1608SECK/J4-PRV; LED-0603; PARTNO 604-APT1608SECKJ4PRV
D-SAT: VERDE - APT1608ZGCK; LED-0603; PARTNO 604-APT1608ZGCK
D-TRIGGER: BLUE - APT1608VBC/D; LED-0603; PARTNO 604-APT1608VBC/D
R3, R15: 10K; 0603-RES; PARTNO 667-ERJ-3EKF1002V
R19: 180; 0603-RES; PARTNO 667-ERJ-3GEYJ181V
R20, R24: 105; 0603-RES; PARTNO 667-ERJ-3EKF1050V
R28: 82; 0603-RES; PARTNO 667-ERJ-3EKF82R0V
SREC: SKRKAEE010; PARTNO 688-SKRKAE
T2, T3: BSS138PS; SOT363; PARTNO 771-BSS138BKS115

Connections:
1.8V: R15.1; also elsewhere on the board
3.3V: D-ON.A; also elsewhere on the board
5V: D-REC.A, D-SAT.A, D-TRIGGER.A; also elsewhere on the board
GND: R28.1, SREC.O, T2.1 (S), T2.4 (S), T3.1 (S); also elsewhere on the board
GP15-LEDSAT: T3.2 (G); also elsewhere on the board
GP44-STARTREC: R15.2, SREC.I; also elsewhere on the board
GP48-LEDTRIGIN: T2.5 (G); also elsewhere on the board
GP165-LEDREC: T2.2 (G); also elsewhere on the board
unnamed: D-ON.C, R28.2
PWRBTN#: R3.2; also elsewhere on the board
V_CH_SYS: R3.1; also elsewhere on the board
X-LEDREC: R19.2, T2.6 (D); also elsewhere on the board
X-LEDREC--: D-REC.C, R19.1
X-SAT: R24.2, T3.6 (D); also elsewhere on the board
X-SAT--: D-SAT.C, R24.1
X-TRIGGER: R20.2, T2.3 (D); also elsewhere on the board
X-TRIGGER--: D-TRIGGER.C, R20.1

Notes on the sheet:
Start Recording
Power button Edison
LED Recording ON/OFF
LED Trigger Event
Satellites (from COMNAV)

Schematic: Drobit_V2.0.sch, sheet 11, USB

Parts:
C22: 22UF; 0603-CAP; PARTNO 810-C1608X5R1A226M
R16: 287; 0603-RES; PARTNO 667-ERJ-3EKF2870V
R17: 10K; 0603-RES; PARTNO 667-ERJ-3EKF1002V
R18: 100k; 0603-RES; PARTNO 594-MCT06030C1003FP5
USB: 10103594-0001LF; POS-5; PARTNO 649-10103594-0001LF
USBREG: MIC2039; SOT23-6; PARTNO 998-MIC2039EYM6T5

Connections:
1.8V: R17.1; also elsewhere on the board
5V: USBREG.1 (VIN); also elsewhere on the board
FAULT: R17.2, USBREG.4 (!FAULT); also elsewhere on the board
GND: C22.2, R16.1, R18.1, USB.5 (GND), USB.PAD1 (GND), USB.PAD2 (GND), USB.PAD3 (GND), USB.PAD4 (GND), USB.PAD5 (GND), USB.PAD6 (GND), USBREG.2 (GND); also elsewhere on the board
unnamed: R16.2, USBREG.5 (ILIM)
PSW: R18.2, USBREG.3 (EN); also elsewhere on the board
USB_DN: USB.2 (D-); also elsewhere on the board
USB_DP: USB.3 (D+); also elsewhere on the board
USB_ID: USB.4 (ID); also elsewhere on the board
USB_VBUS: C22.1, USB.1 (VCC), USBREG.6 (VOUT); also elsewhere on the board

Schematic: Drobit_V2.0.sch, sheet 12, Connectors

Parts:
BATT: CONN_2-1-SFH; SM02B-SFHRS-TF; PARTNO 455-2524-1-ND
EXT-INTERFACE: M40-3100345R; PARTNO 855-M40-3100345R
PWR: JST_PH_G; JST-PH-2-SMT-RA; PARTNO 455-1749-1-ND
R61, R62: 10K; 0603-RES; PARTNO 667-ERJ-3EKF1002V
TRIG-IN: CONN_2-1; JST-GH-2; PARTNO 455-1564-1-ND
TRIG-OUT: CONN_7-1; JST-GH-7; PARTNO 455-1569-1-ND
TVS1, TVS2, TVS3, TVS4, TVS5, TVS6, TVS7, TVS8, TVS9, TVS10: LXES15AAA1-133; 1005; PARTNO 81-LXES15AAA1-133
UART-EXT: CONN_4-1; JST-GH-4; PARTNO 455-1566-1-ND

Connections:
1.8V: TRIG-OUT.6; also elsewhere on the board
3.3V: R61.2, R62.2; also elsewhere on the board
3.3V_LOCAL: TRIG-OUT.1; also elsewhere on the board
5VACC: EXT-INTERFACE.5, UART-EXT.1; also elsewhere on the board
C-EVENT: R61.1, TRIG-OUT.3; also elsewhere on the board
E-GP46-CMD-TRIG-EXT: R62.1, TRIG-IN.1, TVS10.1 (G); also elsewhere on the board
E-UART2RX: TVS2.1 (G), UART-EXT.2; also elsewhere on the board
E-UART2TX: TVS1.2 (IO), UART-EXT.3; also elsewhere on the board
GND: BATT.2, BATT.GND, BATT.GND1 (GND), EXT-INTERFACE.4, PWR.2, PWR.NC1 (3), PWR.NC2 (3), TRIG-IN.2, TRIG-IN.P1 (GND), TRIG-IN.P2 (GND), TRIG-OUT.7, TRIG-OUT.P1 (GND), TRIG-OUT.P2 (GND), TVS1.1 (G), TVS2.2 (IO), TVS3.2 (IO), TVS4.1 (G), TVS5.1 (G), TVS6.1 (G), TVS7.1 (G), TVS8.1 (G), TVS9.1 (G), TVS10.2 (IO), UART-EXT.4, UART-EXT.P1 (GND), UART-EXT.P2 (GND); also elsewhere on the board
GP12_PWM0_TRIG_OUT: TRIG-OUT.2, TVS3.1 (G); also elsewhere on the board
GP44-STARTREC: EXT-INTERFACE.1, TVS9.2 (IO); also elsewhere on the board
SCL_CAM: TRIG-OUT.4, TVS4.2 (IO); also elsewhere on the board
SDA_CAM: TRIG-OUT.5, TVS5.2 (IO); also elsewhere on the board
VCC_RAW_12V: PWR.1; also elsewhere on the board
V_CH_BAT: BATT.1; also elsewhere on the board
X-LEDREC: EXT-INTERFACE.2, TVS8.2 (IO); also elsewhere on the board
X-SAT: EXT-INTERFACE.6, TVS6.2 (IO); also elsewhere on the board
X-TRIGGER: EXT-INTERFACE.3, TVS7.2 (IO); also elsewhere on the board

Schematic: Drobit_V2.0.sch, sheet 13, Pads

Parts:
C-RX2: TPTP08R; TP08R
C-TX2: TPTP08R; TP08R
GP45, GP46: TPTP08R; TP08R
PPS: TPTP08R; TP08R

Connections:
C-COM2RX: C-RX2.TP; also elsewhere on the board
C-COM2TX: C-TX2.TP; also elsewhere on the board
C-EVENT: GP45.TP; also elsewhere on the board
E-GP46-CMD-TRIG-EXT: GP46.TP; also elsewhere on the board
E-GP182_PWM2-PPS: PPS.TP; also elsewhere on the board

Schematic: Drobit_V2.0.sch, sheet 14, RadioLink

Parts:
C14: 1.0uF; 0603-CAP; PARTNO 810-CGA3E1X7R1E105K
C15: 2.2uF; 0603-CAP; PARTNO 810-CGA3E1X5R1C225K
C16: 10nF; 0603-CAP; PARTNO 810-CGA3E2X7R1H103K
DC3VLINK: TPS73501DRBT; SON65P300X300X100-9N; PARTNO 595-TPS73501DRBR
JP_LINK: JUMPER-PAD-2-NOYES_SILK; PAD-JUMPER-2-NO_YES_SILK
LINK: HM-TRLR-S
X1: ANTENNA_U.FL-A-1JB; U.FL-A-1JB; PARTNO 523-A-1JB

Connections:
5VACC: C14.1, DC3VLINK.5 (EN), DC3VLINK.8 (IN); also elsewhere on the board
E-GP13_PWM1-LINKSTATUS: LINK.STATUS; also elsewhere on the board
E-GP49-LINKCONFIG: LINK.CONFIG; also elsewhere on the board
E-UART2RX: LINK.TXD; also elsewhere on the board
E-UART2TX: LINK.RXD; also elsewhere on the board
GND: C14.2, C15.2, C16.2, DC3VLINK.4 (GND), DC3VLINK.GND, DC3VLINK.GND1 (GND), DC3VLINK.GND2 (GND), DC3VLINK.GND3 (GND), DC3VLINK.GND4 (GND), LINK.GND, LINK.GND2 (GND1), LINK.SLEEP, X1.1 (GND), X1.2 (GND); also elsewhere on the board
unnamed: C16.1, DC3VLINK.3 (NR/FB)
unnamed: JP_LINK.2, LINK.RESET, LINK.VCC
unnamed: LINK.ANT, X1.3 (SIGNAL)
V3.3VLINK: C15.1, DC3VLINK.1 (OUT), JP_LINK.1



Board: 4 copper layers, 71.1 x 45.7 mm, 115 parts (110 on the bottom side), 106 nets.

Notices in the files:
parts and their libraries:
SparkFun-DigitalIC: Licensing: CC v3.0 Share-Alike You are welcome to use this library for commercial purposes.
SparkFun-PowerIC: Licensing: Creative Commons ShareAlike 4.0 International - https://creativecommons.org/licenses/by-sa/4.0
